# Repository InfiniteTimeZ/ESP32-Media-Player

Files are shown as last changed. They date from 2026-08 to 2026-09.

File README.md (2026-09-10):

# ESP32 Media Player

A desktop-connected media controller built around an ESP32-S3 touchscreen display.

The project combines a Windows desktop companion with an ESP32 touchscreen to display current media information, album artwork, system audio state, and optional Discord voice-channel information while also providing physical and touchscreen media controls.

<p align="center">
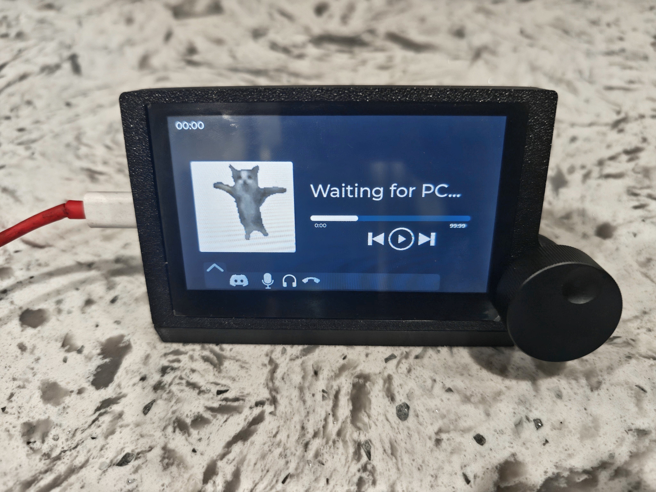
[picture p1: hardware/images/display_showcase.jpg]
ESP32 Media Player
  
</p>

---

## Documentation

| Guide | Purpose |
| --- | --- |
| [Quick Start](docs/QUICK_START.md) | Set up an assembled device |
| [Bill of Materials](hardware/BOM.md) | Parts and reference links |
| [Assembly Guide](hardware/ASSEMBLY.md) | Build the hardware |
| [3D Models](hardware/3d-models/) | Printable housing and stand |
| [Wiring Images](hardware/images/wiring/) | EC11 and CrowPanel pin references |

---

## Features

### Media Display

- Current track title and artist
- 250 × 250 album artwork
- Playback position and duration
- Dynamic interface colors derived from album artwork
- Current system time
- Windows volume and mute state
- Play/pause synchronization

### Controls

**EC11 rotary encoder**
- Rotate — adjust Windows system volume
- Single press — play/pause
- Double press — mute/unmute Windows audio

**Touchscreen**
- Play/pause
- Previous/next track
- Seeking
- Discord voice controls when Discord integration is enabled

### Discord Integration

Optional Discord integration provides:

- Current voice-channel name
- Voice-channel members
- User avatars
- Mute/deafen state
- Voice-channel controls

The interface displays up to **15 voice-channel users** at once.

---

## How It Works

The project is split into two applications:

1. A **Windows desktop companion**
2. Firmware running on the **ESP32-S3 display**

```text
                         Windows PC
┌────────────────────────────────────────────────────────────┐
│                    Desktop Companion                       │
│                                                            │
│  Windows Media ──► media.py                                │
│  Windows Audio ──► Pycaw                                   │
│  Discord ────────► discord_client.py / network.py          │
│                        │                                   │
│                        ▼                                   │
│                    hardware.py                             │
└───────────────────────────┬────────────────────────────────┘
                            │ USB Serial @ 230400 baud
                            ▼
┌────────────────────────────────────────────────────────────┐
│                         ESP32-S3                           │
│                serial_protocol.cpp                         │
│                         │                                  │
│              ┌──────────┴──────────┐                       │
│              ▼                     ▼                       │
│     media_display.cpp       discord_ui.cpp                 │
│                                                            │
│   Touchscreen / Encoder ──► commands back to Windows       │
└────────────────────────────────────────────────────────────┘
```

The desktop companion retrieves Windows and Discord state, sends it to the ESP32 over USB serial, and receives control commands from the display.

---

## Quick Start

1. Flash the ESP32 using the [browser firmware installer](https://infinitetimez.github.io/ESP32-Media-Player/).
2. Download the latest Windows companion from GitHub Releases.
3. Connect the display over USB.
4. Run the desktop companion.
5. Optionally enable Discord integration.

No Python or PlatformIO installation is required when using the prebuilt release files.

For installation details and troubleshooting, continue with the **[Quick Start Guide](docs/QUICK_START.md)**.

---

## Building the Hardware

The repository includes the enclosure files, wiring references, and documentation required to recreate the reference unit.

The reference build uses:

- ELECROW CrowPanel Advance 4.3" 800 × 480 ESP32 HMI Display
- EC11 rotary encoder
- 32 × 13 mm aluminum knob
- M3 heat-set inserts and screws
- Square magnets
- 22 AWG solid-core wire
- Printed display housing and stand

For exact parts, dimensions, and purchase links, see the **[Bill of Materials](hardware/BOM.md)**.

For connector trimming, heat-set inserts, magnet installation, encoder wiring, and final assembly, continue with the **[Assembly Guide](hardware/ASSEMBLY.md)**.

---

## EC11 Encoder Wiring

| EC11 Pin / Function | ESP32 Connection |
| --- | --- |
| A | GPIO 19 |
| B | GPIO 20 |
| C / Common | GND |
| Push switch | GPIO 8 |
| Remaining switch terminal | GND |

The push-switch terminals are interchangeable. If clockwise rotation decreases volume instead of increasing it, swap **A** and **B**.

See the labeled references in [`hardware/images/wiring/`](hardware/images/wiring/) or the **[Assembly Guide](hardware/ASSEMBLY.md)** for full wiring notes.

---

## Serial Protocol

Desktop-to-ESP32 application traffic uses a framed binary protocol:

```text
A5 5A | TYPE | uint32 LE LENGTH | PAYLOAD
```

| Type | Payload | Purpose |
| --- | --- | --- |
| `R` | None | ESP32 readiness |
| `T` | JSON | Track/media state |
| `I` | JPEG | Album artwork |
| `U` | JSON | Discord voice roster |
| `A` | Index + JPEG | Discord user avatar |
| `D` | State bytes | Discord mute/deafen state |
| `N` | Text | Discord voice-channel name |

The firmware parser can recover from incomplete or corrupted data by searching for the next valid frame boundary. Large image packets are sent in smaller chunks to avoid overwhelming the ESP32 receive path.

---

## Project Structure

```text
ESP32-Media-Player/
├── desktop-companion/
│   ├── assets/
│   ├── main.py
│   ├── hardware.py
│   ├── media.py
│   ├── network.py
│   ├── discord_client.py
│   ├── config.py
│   ├── requirements.txt
│   └── PyInstaller spec files
│
├── firmware/
│   ├── boards/
│   ├── include/
│   ├── src/
│   │   ├── components/
│   │   ├── images/
│   │   ├── screens/
│   │   ├── main.cpp
│   │   ├── serial_protocol.cpp
│   │   ├── media_display.cpp
│   │   ├── discord_ui.cpp
│   │   └── music_player_logic.c
│   ├── partitions.csv
│   ├── platformio.ini
│   ├── sdkconfig.defaults
|   └── sdkconfig.defaults.esp32s3
│
├── hardware/
│   ├── 3d-models/
│   ├── images/
│   ├── ASSEMBLY.md
│   └── BOM.md
│
├── docs/
│   ├── firmware/
│   ├── index.html
│   ├── manifest.json
│   └── QUICK_START.md
│
├── README.md
├── LICENSE
└── .gitignore
```

---

## Running From Source

### Desktop Companion

Requirements:

- Windows
- Python 3
- Discord desktop client if using Discord integration

```powershell
cd desktop-companion
python -m venv .venv
.\.venv\Scripts\Activate.ps1
pip install -r requirements.txt
python main.py
```

### ESP32 Firmware

The firmware is built with PlatformIO:

```bash
cd firmware
pio run
pio run --target upload
```

Serial communication uses **230400 baud**.

---

## Discord Setup

Discord integration is optional.

1. Create an application in the [Discord Developer Portal](https://discord.com/developers/applications).
2. Copy the **Application ID** and **Client Secret**.
3. Add this OAuth2 redirect URI:

```text
http://127.0.0.1
```

4. Enable **Discord Integration** from the desktop companion's system-tray menu.
5. Enter the requested credentials and restart the companion.

> Keep the Client Secret private. Do not commit it to GitHub or include it in screenshots.

---

## Releases

Prebuilt Windows builds and merged ESP32 firmware images are available on the GitHub Releases page.

The ESP32 can also be flashed directly using the [browser firmware installer](https://infinitetimez.github.io/ESP32-Media-Player/).

---

## Known Limitations

- The desktop companion currently supports Windows only.
- Firmware configuration targets the reference ELECROW display hardware.
- The Discord interface displays up to 15 visible voice-channel users.
- Album artwork depends on thumbnail data supplied by the active Windows media application.

---

## Project Status

This was primarily a summer project, and since I'm a student, updates may be inconsistent depending on how busy I am.

If you run into an issue, feel free to open one and I'll get to it when I can.

---

## License

Licensed under the GNU General Public License v3.0. See [`LICENSE`](LICENSE) for details.

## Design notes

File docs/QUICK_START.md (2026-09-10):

# Quick Start

This guide continues from the main README and is intended for users who already have the ESP32 Media Player assembled.

## 1. Flash the ESP32

The easiest installation method is the [browser firmware installer](https://infinitetimez.github.io/ESP32-Media-Player/).

Use a current desktop version of **Google Chrome** or **Microsoft Edge**.

1. Connect the CrowPanel to the computer over USB.
2. Close the desktop companion and any serial-monitoring software.
3. Open the browser installer.
4. Click **Install Firmware**.
5. Select the ESP32-S3 device.
6. Wait for installation to finish and allow the display to restart.

The installer flashes the complete merged firmware image automatically. No PlatformIO installation or manual flash offsets are required.

### Manual Firmware Installation

The merged firmware image is also available from GitHub Releases.

If flashing manually, write the merged image beginning at:

```text
0x0000
```

## 2. Install the Windows Companion

Download the latest Windows executable from GitHub Releases and run it.

The application runs from the Windows system tray.

## 3. Connect the Display

Connect the ESP32 Media Player over USB. The desktop companion automatically searches for the device and establishes the serial connection.

Once connected, the display should begin showing media information, album artwork, playback position, system volume, and the current time.

## 4. Controls

### Rotary Encoder

- Rotate — change Windows volume
- Single press — play/pause
- Double press — mute/unmute Windows audio

### Touchscreen

- Play/pause
- Previous/next track
- Seeking
- Supported Discord voice controls

## 5. Optional Discord Integration

Enable **Discord Integration** from the companion's system-tray menu and enter your Discord application credentials when prompted.

Discord must be running locally.

For Discord application setup, see the **Discord Setup** section in the main README.

## Troubleshooting

### Display is not connecting

- Confirm the ESP32 is connected over USB.
- Close any other program using the ESP32 serial port.
- Restart the desktop companion.
- Disconnect and reconnect the ESP32.

### Display connects but does not update

Restart the desktop companion and reconnect the display.

### Album artwork is stale

Some Windows media applications provide delayed thumbnail data. The companion retries artwork retrieval several times when a new track is detected, but stale artwork can still occur.

### Discord information is missing

- Confirm Discord is running.
- Confirm Discord integration is enabled.
- Verify the Discord application credentials.
- Restart the desktop companion after first-time setup.

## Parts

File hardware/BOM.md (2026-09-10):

# Bill of Materials

This page continues from the hardware overview in the main README and lists the parts used in the reference ESP32 Media Player build.

## Main Components

| Component | Qty. | Specification | Reference Link | Notes |
| --- | ---: | --- | --- | --- |
| ESP32 Touch Display | 1 | ELECROW CrowPanel Advance 4.3", 800 × 480 IPS touch display | [ELECROW](https://www.elecrow.com/crowpanel-advance-4-3-hmi-esp32-800x480-ai-display-ips-touch-artificial-intelligent-screen.html) | Reference display hardware |
| Rotary Encoder | 1 | EC11 with push switch, 15 mm D-shaft | [Amazon](https://www.amazon.com/dp/B07D3D64X7) | Volume, play/pause, and mute |
| Encoder Knob | 1 | 32 × 13 mm aluminum knob for 6 mm shaft | [Amazon](https://www.amazon.com/dp/B07X7RDQ1W) | Fits the reference EC11 |
| M3 Heat-Set Inserts | 4 | M3 brass threaded inserts | [Amazon](https://www.amazon.com/dp/B0FWWW8VP1) | Used with enclosure mounting points |
| M3 × 12 Screws | 4 | M3 Phillips machine screws | [Amazon](https://www.amazon.com/dp/B0D1CRFR6Z) | Used with the heat-set inserts |
| Square Magnets | 2 | 1.26" × 1.26", 2 mm thick | [Amazon](https://www.amazon.com/dp/B0GQ47BZJS) | Housing-to-stand attachment |
| Hookup Wire | As needed | 22 AWG solid-core wire | [Amazon](https://www.amazon.com/dp/B07TX6BX47) | Encoder and internal wiring |

## 3D-Printed Parts

| Part | Qty. | File |
| --- | ---: | --- |
| Display Housing | 1 | [`Display_Housing_Print.stl`](3d-models/Display_Housing_Print.stl) |
| Stand | 1 | [`Stand_Print.stl`](3d-models/Stand_Print.stl) |

Reference printing:

- **Material:** PETG-HF
- **Supports:** not required
- **Orientation:** STL files are already oriented as used for the reference prints

## Additional Notes

**Magnets:** The reference magnets include adhesive. Approximately **1 mm double-sided tape** can be used as a replacement. Confirm magnet orientation before permanent installation.

**Display connector clearance:** The four beige connector housings on the CrowPanel must be trimmed to fit inside the enclosure. Advanced builders can desolder the connectors and wire directly to the PCB instead.

For wiring, heat-set insert installation, connector trimming, and final assembly, continue with the **[Assembly Guide](ASSEMBLY.md)**.

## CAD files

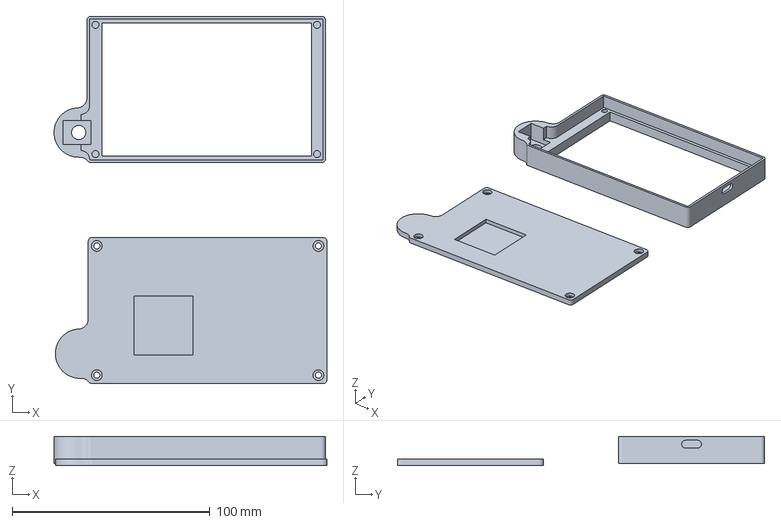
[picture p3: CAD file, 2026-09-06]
hardware/3d-models/Display_Housing.3mf
138.0 x 185.8 x 14.7 mm

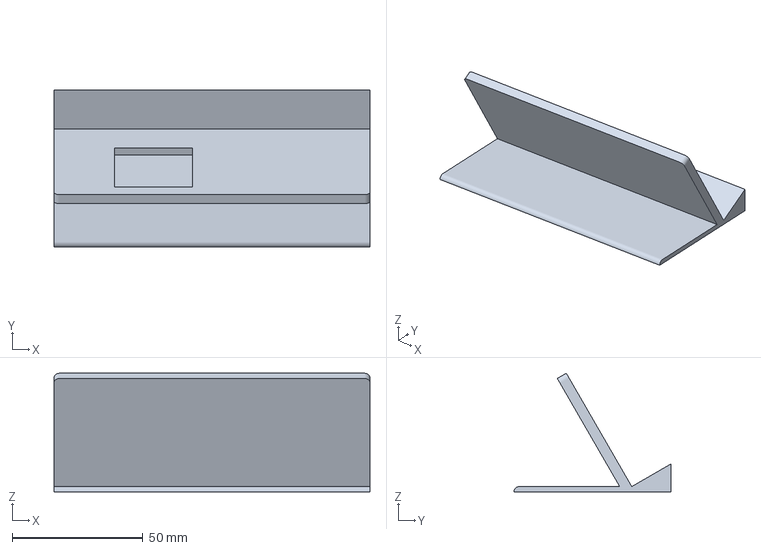
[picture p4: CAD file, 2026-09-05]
hardware/3d-models/Stand_Print.3mf
120.7 x 60.0 x 45.3 mm

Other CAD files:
hardware/3d-models/Display_Housing_Print.stl
hardware/3d-models/Complete_Housing_Assembly.f3d
hardware/3d-models/Stand_Print.stl

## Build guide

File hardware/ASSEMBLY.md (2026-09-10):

# Hardware Assembly Guide

This guide continues from the hardware overview in the main README and covers the reference ESP32 Media Player assembly.

For exact parts and purchase links, see the **[Bill of Materials](BOM.md)**.

## Tools

Recommended tools:

- Soldering iron
- Small Phillips screwdriver
- Flush cutters or hobby knife
- Heat-set insert tip or suitable soldering-iron tip
- Wire strippers
- Solder

## 1. Print the Enclosure

Print both files from [`3d-models/`](3d-models/):

- `Display_Housing_Print.stl`
- `Stand_Print.stl`

Reference print setup:

- **Material:** PETG-HF
- **Supports:** not required
- **Orientation:** the STL files are already oriented as used for the reference prints

Other suitable materials should also work, though support requirements may vary.

## 2. Prepare the Display Board

The four beige connector housings on the display board are too tall to fit inside the printed enclosure.

Carefully trim the housings until the board clears the inside of the case.

**Advanced alternative:** desolder the connector housings and wire directly to the PCB. This provides more clearance but carries a greater risk of damaging the board.

## 3. Install the Heat-Set Inserts

Install **4 M3 heat-set inserts**.

For PETG-HF, approximately **270 °C** worked well.

- Apply light, steady pressure.
- Allow the heat to soften the plastic rather than forcing the insert.
- Stop once the insert is flush.
- Let the plastic cool before installing screws.

Adjust the temperature as needed for the filament being used.

## 4. Install the Magnets

Use **2 square magnets** measuring:

- 1.26 in × 1.26 in
- 2 mm thick

Install one magnet in the housing and one in the stand. Dry-fit both parts first and verify that the magnets attract each other before attaching them permanently.

The reference magnets include adhesive. If you need replacement adhesive, use about **1 mm double-sided tape**. Thinner adhesive is better for a flush magnet fitment.
## 5. Wire the EC11 Encoder

| Encoder Pin / Function | ESP32 |
| --- | --- |
| A | GPIO 19 |
| B | GPIO 20 |
| C / Common | GND |
| D or E / Push switch | GPIO 8 |
| Remaining switch terminal | GND |

The two push-switch terminals are interchangeable.

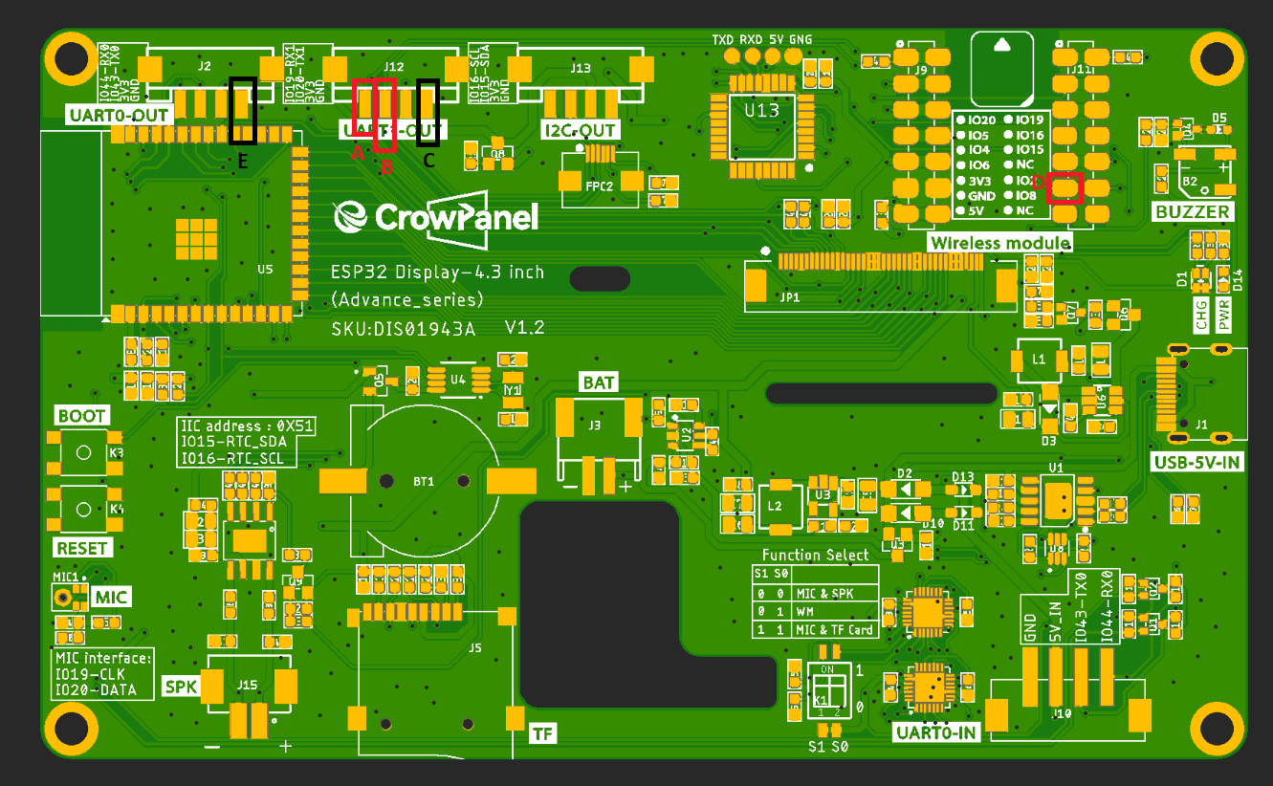
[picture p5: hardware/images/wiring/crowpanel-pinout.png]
CrowPanel GPIO reference


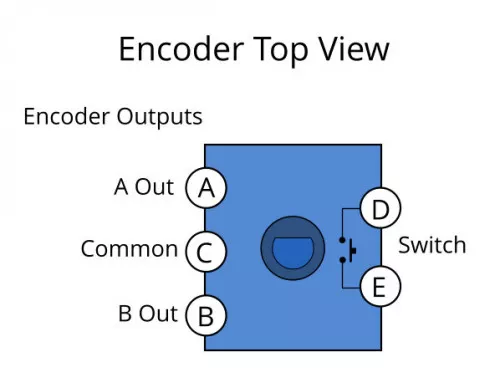
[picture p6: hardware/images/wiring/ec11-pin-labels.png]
EC11 labeled pins


> If clockwise rotation lowers volume instead of raising it, swap A and B.

## 6. Mount the Encoder and Knob

1. Secure the EC11 using its washer and nut.
2. Confirm the shaft rotates freely and the push action is unobstructed.
3. Install the 32 × 13 mm aluminum knob onto the 6 mm shaft.

## 7. Mount the Display

1. Confirm the trimmed connectors or direct wiring clear the enclosure.
2. Position the display without pinching any wires.
3. Check that internal wiring cannot short against the board.
4. Secure the display using the M3 hardware.

## 8. Flash and Test

Continue with the **[Quick Start Guide](../docs/QUICK_START.md)**.

Verify:

- Display boots
- Desktop companion connects
- Track information and album art update
- Encoder controls volume, play/pause, and mute
- Touchscreen controls work
- Discord UI updates correctly when enabled

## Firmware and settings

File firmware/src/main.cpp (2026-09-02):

#include "pins_config.h"
#include "LovyanGFX_Driver.h"
#include <Arduino.h>
#include <lvgl.h>
#include <Wire.h>
#include <SPI.h>
#include <stdbool.h>
#include "ui.h"
#include "music_player_logic.h"
#include "serial_protocol.h"
#include "discord_ui.h"
#include "media_display.h"

LGFX gfx;
static uint8_t *buf;
static uint8_t *buf1;
constexpr uint32_t LVGL_BUFFER_LINES = 60;
uint16_t touch_x, touch_y;
uint32_t vol_lockout_timer = 0;

#define ENC_PIN_A 19
#define ENC_PIN_B 20
#define ENC_PIN_D 8

constexpr uint32_t DOUBLE_CLICK_TIME = 450;

volatile int32_t encoder_counter = 0;
volatile uint8_t encoder_history = 0;
int32_t last_pos = 0;
int currentVolume = 25;

bool is_system_muted = false; 

static const int8_t KNOB_STATES[] = {0, -1, 1, 0, 1, 0, 0, -1, -1, 0, 0, 1, 0, 1, -1, 0};

void uart_error(hardwareSerial_error_t error){
  Serial.printf("UART ERROR: %d\n", error);
}


void IRAM_ATTR encoder_isr() {
    encoder_history <<= 2;
    encoder_history |= (digitalRead(ENC_PIN_A) << 1) | digitalRead(ENC_PIN_B);
    int8_t movement = KNOB_STATES[encoder_history & 0x0F];
    if (movement != 0) {
        encoder_counter += movement;
    }
}


void setup_encoder() {
    pinMode(ENC_PIN_A, INPUT_PULLUP);
    pinMode(ENC_PIN_B, INPUT_PULLUP);
    pinMode(ENC_PIN_D, INPUT_PULLUP);
    attachInterrupt(digitalPinToInterrupt(ENC_PIN_A), encoder_isr, CHANGE);
    attachInterrupt(digitalPinToInterrupt(ENC_PIN_B), encoder_isr, CHANGE);
}


void my_encoder_read(lv_indev_t *indev, lv_indev_data_t *data) {
    int32_t diff = encoder_counter - last_pos;
    last_pos = encoder_counter;
    if (diff > 0) data->enc_diff = 1;
    else if (diff < 0) data->enc_diff = -1;
    else data->enc_diff = 0;
    data->state = (digitalRead(ENC_PIN_D) == LOW) ? LV_INDEV_STATE_PRESSED : LV_INDEV_STATE_RELEASED;
}


void my_disp_flush(lv_display_t *disp, const lv_area_t *area, uint8_t *px_map) {
    uint32_t w = area->x2 - area->x1 + 1;
    uint32_t h = area->y2 - area->y1 + 1;

    gfx.startWrite();
    gfx.pushImageDMA(area->x1, area->y1, w, h, (lgfx::rgb565_t *)px_map);
    gfx.endWrite(); 
    
    lv_display_flush_ready(disp);
}


void my_touchpad_read(lv_indev_t *indev, lv_indev_data_t *data) {
    data->state = LV_INDEV_STATE_REL;
    bool touched = gfx.getTouch(&touch_x, &touch_y);
    if (touched) {
        data->state = LV_INDEV_STATE_PR;
        data->point.x = touch_x;
        data->point.y = touch_y;
    }
}


uint32_t my_tick_get_cb() {
    return millis();
}


 bool i2cScanForAddress(uint8_t address) {
    Wire.beginTransmission(address);
    return (Wire.endTransmission() == 0);
}


void sendI2CCommand(uint8_t command) {
    uint8_t error;
    Wire.beginTransmission(0x30);
    Wire.write(command);
    error = Wire.endTransmission();
    if (error == 0) {
        Serial.print("command 0x");
        Serial.print(command, HEX);
        Serial.println(" Sent successfully");
    } else {
        Serial.print("Command sent error, error code:");
        Serial.println(error);
    }
}


 void handle_volume_logic() {
    static int32_t last_volume_pos = 0;
    static uint32_t last_click_time = 0; 
    
    int32_t current_pos = encoder_counter / 4;

    static uint32_t interaction_timer = 0;
    static int current_opacity = 0; 
    static bool is_active = false;

    if (current_pos != last_volume_pos) {
        int32_t diff = current_pos - last_volume_pos;
        last_volume_pos = current_pos;

        uint32_t current_time = millis();
        uint32_t time_between_clicks = current_time - last_click_time;
        last_click_time = current_time;

        int step_multiplier = 1;  
        
        if (time_between_clicks < 50) {
            step_multiplier = 10; 
        } else if (time_between_clicks < 120) {
            step_multiplier = 5;  
        } else if (time_between_clicks < 250) {
            step_multiplier = 2;  
        }

        currentVolume += (diff * step_multiplier);
 
        if (currentVolume > 100) currentVolume = 100;
        if (currentVolume < 0) currentVolume = 0;

        Serial.print("CMD:VOL:");
        Serial.println(currentVolume);

        if (is_system_muted) {
            is_system_muted = false;
            update_mute_visuals();
        }

        vol_lockout_timer = millis();

        lv_bar_set_value(ui_Bar1, currentVolume, LV_ANIM_OFF);

        char str_buf[8];
        snprintf(str_buf, sizeof(str_buf), "%d%%", currentVolume);
        lv_label_set_text(ui_Vol_Percent, str_buf);

        if (!is_active) {
            lv_obj_remove_flag(ui_Volume_Panel, LV_OBJ_FLAG_HIDDEN);
            is_active = true;
        }

        interaction_timer = millis();
    }

    if (is_active) {
        uint32_t time_elapsed = millis() - interaction_timer;

        if (time_elapsed < 2000) {
            if (current_opacity < 255) {
                current_opacity += 51; 
                if (current_opacity > 255) current_opacity = 255;
                lv_obj_set_style_opa(ui_Volume_Panel, current_opacity, LV_PART_MAIN);
            }
        } else {
            if (current_opacity > 0) {
                current_opacity -= 25; 
                if (current_opacity < 0) current_opacity = 0;
                lv_obj_set_style_opa(ui_Volume_Panel, current_opacity, LV_PART_MAIN);
            } else {
                lv_obj_add_flag(ui_Volume_Panel, LV_OBJ_FLAG_HIDDEN);
                is_active = false;
            }
        }
    }
}


void setup_serial(){
    size_t rx_size = Serial.setRxBufferSize(1024 * 40);
    Serial.begin(230400);  
    Serial.setRxFIFOFull(64);
    Serial.onReceiveError(uart_error);
    Serial.printf("Serial RX buffer allocated: %u bytes\n", rx_size);
}


void setup_controllers(){
    Wire.begin(15, 16);
    delay(50);

    while (true) {
        if (i2cScanForAddress(0x30) && i2cScanForAddress(0x5D)) {
            Serial.println("Both controllers detected");
            break;
        } else {
            sendI2CCommand(250);
            pinMode(1, OUTPUT);
            digitalWrite(1, LOW);
            delay(120);
            pinMode(1, INPUT);
            delay(100);
        }
    }
    sendI2CCommand(0);
}

void setup_display(){
    
    gfx.init();
    gfx.initDMA(); 
    
    gfx.startWrite();
    gfx.fillScreen(TFT_BLACK);
    gfx.endWrite();

    lv_init();
    lv_tick_set_cb(my_tick_get_cb);

    constexpr size_t buffer_size = LCD_H_RES * LVGL_BUFFER_LINES * sizeof(uint16_t);
    
    buf = static_cast<uint8_t *>(heap_caps_malloc(buffer_size, MALLOC_CAP_INTERNAL | MALLOC_CAP_DMA));
    buf1 = static_cast<uint8_t *>(heap_caps_malloc(buffer_size, MALLOC_CAP_INTERNAL | MALLOC_CAP_DMA));
    
    if (buf == nullptr || buf1 == nullptr) {
        Serial.println("Failed to allocate INTERNAL LVGL display buffers");
        abort();
    }

    lv_display_t *display = lv_display_create(LCD_H_RES, LCD_V_RES);
    lv_display_set_color_format(display, LV_COLOR_FORMAT_RGB565);
    lv_display_set_flush_cb(display, my_disp_flush);
    lv_display_set_buffers(display, buf, buf1, buffer_size, LV_DISPLAY_RENDER_MODE_PARTIAL);

    lv_indev_t *indev = lv_indev_create();
    lv_indev_set_type(indev, LV_INDEV_TYPE_POINTER);
    lv_indev_set_read_cb(indev, my_touchpad_read);

    setup_encoder();
    
    lv_indev_t *encoder_indev = lv_indev_create();
    lv_indev_set_type(encoder_indev, LV_INDEV_TYPE_ENCODER);
    lv_indev_set_read_cb(encoder_indev, my_encoder_read);
}

void setup_ui(){
    delay(100);
    gfx.fillScreen(TFT_BLACK);

    ui_init();
    register_screen_switch_handlers();
    lv_obj_set_parent(ui_Volume_Panel, lv_layer_top());
    lv_obj_set_parent(ui_TimeLabel, lv_layer_top());
    lv_obj_set_style_text_color(ui_TimeLabel, lv_color_hex(0xFFFFFF), LV_PART_MAIN);
    lv_obj_add_event_cb(ui_SongPositionSlider, track_slider_cb, LV_EVENT_PRESSED, NULL);
    lv_obj_add_event_cb(ui_SongPositionSlider, track_slider_cb, LV_EVENT_RELEASED, NULL);
    music_player_init();
    
    lv_obj_add_flag(ui_Volume_Panel, LV_OBJ_FLAG_HIDDEN);
    init_serial_protocol();
    init_media_display();
    init_discord_ui_buffers();

    char str_buf[8];
    snprintf(str_buf, sizeof(str_buf), "%d%%", currentVolume);
    lv_label_set_text(ui_Vol_Percent, str_buf);

    last_pos = encoder_counter;
}

void signal_ready(){

    while (Serial.available() > 0) {
        Serial.read();
    }
      
    delay(50);
    Serial.println();
    Serial.println("ESP32_READY");
}


void handle_encoder_button(){
    static int lastButtonState = HIGH;
    static uint32_t last_button_click_time = 0;
    static bool pending_single_click = false;
   

    int currentButtonState = digitalRead(ENC_PIN_D); 

    if (currentButtonState != lastButtonState) {
        delay(10); 
        currentButtonState = digitalRead(ENC_PIN_D); 
        if (currentButtonState != lastButtonState) {
            lastButtonState = currentButtonState;
            
            if (currentButtonState == LOW) { 
                if (pending_single_click && (millis() - last_button_click_time < DOUBLE_CLICK_TIME)) {
                    Serial.println("CMD:MUTE");
                    is_system_muted = !is_system_muted;
                    update_mute_visuals();
                    pending_single_click = false;

                } else {
                     pending_single_click = true;
                }
                 last_button_click_time = millis();
            }
        }
       
    }  
    if (pending_single_click && (millis() - last_button_click_time > DOUBLE_CLICK_TIME)) {
        Serial.println("CMD:TOGGLE");
        pending_single_click = false;    
    }
}


 void setup() {
    setup_serial();
    setup_controllers();
    setup_display();
    setup_ui();
    
    Serial.println("Setup done");

    signal_ready(); 
}

void loop() {
    lv_timer_handler();
    handle_volume_logic();
    handle_serial_input();
    handle_encoder_button();

    delay(1);
}

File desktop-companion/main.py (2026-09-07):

import asyncio
import logging
import os
import shutil
import sys
import threading
import time

from PIL import Image
import pystray
from pystray import MenuItem as item

import config
import hardware
import media
import network


is_paused = False
logger = logging.getLogger(__name__)

class MediaSyncState:
    def __init__(self):
        self.last_processed_track = None
        self.last_resync_time = 0
        self.last_known_position = 0
        self.last_sent_signature = None


def configure_logging():
    logging.basicConfig(
        level=logging.INFO,
        format="%(asctime)s | %(levelname)-8s | %(name)s | %(message)s",
        datefmt="%H:%M:%S",
    )


def track_signature(track_info):
    return (track_info.get("title"), track_info.get("artist"), track_info.get("album"), track_info.get("duration"), track_info.get("playback_status"), track_info.get("volume"), track_info.get("is_muted"), track_info.get("time"))


async def connect_hardware():
    if not hardware.connect():
        await asyncio.sleep(2)
        return False

    logger.info("Serial connected; waiting for ESP32 ready signal")

    deadline = time.monotonic() + 8
    next_probe = 0

    while time.monotonic() < deadline:
        now = time.monotonic()
                        
        #Retry slowly enough that an interrupted parser has time to reach
        # its 1.5 second stall recovery before next probe
        if now >= next_probe:
            hardware.request_ready()
            logger.info("Sent ESP32 readiness probe")
            next_probe = now + 2.0
            
        lines = hardware.read_incoming()
            
        if any("ESP32_READY" in line for line in lines):
            logger.info("ESP32 ready signal received")
            hardware.mark_ready_for_sync()
            network.resync_hardware()
            return True

        await asyncio.sleep(0.1)

    logger.warning("ESP32 ready signal was not received before timeout; reconnecting")

    hardware.disconnect()
    await asyncio.sleep(1)
    return False


async def handle_incoming_commands(session_manager, discord_rpc):
    incoming_commands = hardware.read_incoming()
    for clean_line in incoming_commands:
        logger.debug("UART received: %s", clean_line)

        if "Serial stall detected" in clean_line or "Corrupt stream detected" in clean_line  or "Serial packet timeout" in clean_line or "Invalid packet" in clean_line or "JPEG decode failed" in clean_line:

            logger.warning("ESP32 serial parser reported: %s", clean_line)
            continue

        if clean_line in ["CMD:NEXT", "CMD:PREV", "CMD:TOGGLE"] or clean_line.startswith("CMD:SEEK:"):
            await media.handle_media_command(session_manager, clean_line)

        elif clean_line == "CMD:MUTE":
            media.toggle_windows_mute()

        elif clean_line.startswith("CMD:VOL:"):
            try:
                volume = int(clean_line.split(":")[2])
                media.set_windows_volume(volume)
            except ValueError:
                logger.warning("Received invalid volume command: %s", clean_line)

        elif clean_line.startswith("CMD:TOGGLE_") or clean_line == "CMD:LV_CALL":
            asyncio.create_task(network.handle_discord_commands(discord_rpc, clean_line))


async def sync_current_media(session_manager, state):
    track_info, state.last_processed_track, new_art = (await media.get_current_track_info(session_manager, state.last_processed_track))

    if track_info:
        sig = track_signature(track_info)
        now = asyncio.get_running_loop().time()

        current_pos = track_info["position"]
        is_seek = abs(current_pos - state.last_known_position) > 3.0         
                
        if sig != state.last_sent_signature:
            hardware.send_track_info(track_info)
            state.last_sent_signature = sig
            state.last_resync_time = now
        elif is_seek or (now - state.last_resync_time) > 5: 
            hardware.send_track_info(track_info)
            state.last_resync_time = now
    
        state.last_known_position = current_pos
    
    if new_art: 
        hardware.send_album_art(new_art)


async def main_loop():

    hardware.start()
    media.start()

    sync_state = MediaSyncState()
    session_manager = await media.MediaManager.request_async()
    

    discord_rpc = None
    if config.app_config.get("use_discord"):
        discord_rpc = await network.init_discord_rpc()

    while True:
        if is_paused:
            hardware.disconnect()
            await asyncio.sleep(1)
            continue
                
        if not hardware.is_connected():
            if not await connect_hardware():
                continue
                     
            sync_state.last_sent_signature = None
            sync_state.last_processed_track = None
            sync_state.last_resync_time = asyncio.get_running_loop().time()

        await handle_incoming_commands(session_manager, discord_rpc)
        await sync_current_media(session_manager, sync_state)

        await asyncio.sleep(0.6)



def toggle_pause(icon, item):
    global is_paused
    is_paused = not item.checked


def toggle_discord(icon, item):
    enabled = not item.checked

    if enabled:
        if not config.app_config.get("discord_client_id") or not config.app_config.get("discord_client_secret"):
            def enable_discord_callback():
                config.app_config["use_discord"] = enabled
                config.save_config()
                logger.info("Discord credentials saved; restart required")
            config.prompt_for_discord_credentials(enable_discord_callback)
            return
    config.app_config["use_discord"] = enabled
    config.save_config()
    logger.info("Discord integration setting updated; restart required")


def set_windows_startup(enabled):
    startup_folder = os.path.join(os.getenv('APPDATA'), r"Microsoft\Windows\Start Menu\Programs\Startup")
    exe_name = os.path.basename(sys.executable)
    startup_path = os.path.join(startup_folder, exe_name)

    if enabled:
        try:
            shutil.copy(sys.executable, startup_path)
            logger.info("Enabled Windows startup")
        except Exception:
            logger.exception("Failed to enable Windows startup")

    elif os.path.exists(startup_path):
        try:
            os.remove(startup_path)
            logger.info("Disabled Windows startup")
        except Exception:
            logger.exception("Failed to disable Windows startup")


def toggle_startup(icon, item):
    enabled = not item.checked

    config.app_config["run_on_startup"] = enabled
    config.save_config()

    set_windows_startup(enabled)



def quit_app(icon, item):
    icon.stop()
    os._exit(0)


def resource_path(relative_path):
    if hasattr(sys, "_MEIPASS"):
        return os.path.join(sys._MEIPASS, relative_path)
    return os.path.join(os.path.dirname(__file__), relative_path)
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

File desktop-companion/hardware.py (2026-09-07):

import json
import logging
import queue
import struct
import threading
import time

import serial
import serial.tools.list_ports

ESP32_VID = 0x1A86
KNOWN_CH340_PIDS = {0x7522, 0x7523, 0x5523}
_PACKET_MAGIC = b"\xA5\x5A"

connection = None
uart_buffer = ""
_ready_for_sync = False
_writer_thread = None
_latest_album_art_packet = None
_album_art_token_queued = False
logger = logging.getLogger(__name__)

_write_lock = threading.RLock()
_write_queue = queue.Queue()
_album_art_lock = threading.Lock()
_album_art_token = object()


def _build_packet(packet_type, payload=b""):
    if not isinstance(packet_type, bytes) or len(packet_type) != 1:
        raise ValueError("packet_type must be exactly one byte")

    return (_PACKET_MAGIC + packet_type + struct.pack("<I", len(payload)) + payload)


def _write_packet(serial_connection, data):
    chunk_size = 128

    for i in range(0, len(data), chunk_size):
        chunk = data[i:i + chunk_size]
        serial_connection.write(chunk)

        if i + chunk_size < len(data):
            time.sleep(0.005)

    serial_connection.flush()


def _clear_write_queue():
    while True:
        try:
            _write_queue.get_nowait()
            _write_queue.task_done()
        except queue.Empty:
            break



def _clear_pending_album_art():
    global _latest_album_art_packet, _album_art_token_queued

    with _album_art_lock:
        _latest_album_art_packet = None
        _album_art_token_queued = False


def _serial_writer():
    global _latest_album_art_packet, _album_art_token_queued

    while True:
        item = _write_queue.get()
        serial_connection = None

        try:
            if item is None:
                break

            if item is _album_art_token:
                with _album_art_lock:
                    data = _latest_album_art_packet
                    _latest_album_art_packet = None
                    _album_art_token_queued = False

                if data is None:
                    continue

                is_large = True

            else:
                is_large, data = item

            with _write_lock:
                serial_connection = connection
            
                if (serial_connection is None or not serial_connection.is_open):
                    continue

                logger.debug( "Sending serial packet: %d bytes, large=%s", len(data), is_large)    
                _write_packet(serial_connection, data)
                if is_large:
                    time.sleep(0.10)
            
        except(serial.SerialException, OSError) as exc:
            logger.warning("ESP32 serial connection lost: %s", exc)
            disconnect(expected_connection=serial_connection)
                        
        finally:
            _write_queue.task_done()


def start():
    global _writer_thread

    if _writer_thread is not None and _writer_thread.is_alive():
        return

    _writer_thread = threading.Thread(target=_serial_writer, name="esp32-serial-writer", daemon=True)
    _writer_thread.start()
    logger.debug("ESP32 serial writer started")


def find_esp32_port():
    ports = serial.tools.list_ports.comports()
    for port in ports:
        if port.vid == ESP32_VID and port.pid in KNOWN_CH340_PIDS:
            return port.device
    return None


def connect():
    global connection, uart_buffer, _ready_for_sync

    if connection and connection.is_open:
        return True

    port_name = find_esp32_port()

    if not port_name:
        return False

    with _write_lock:
        try:
            _ready_for_sync = False
            uart_buffer = ""
            _clear_write_queue()
            _clear_pending_album_art()
            connection = serial.Serial(port_name, 230400, timeout=1)
            logger.info("Connected to ESP32 on %s", port_name)
            return True
        except serial.SerialException:
            logger.exception("Failed to connect to ESP32 on %s", port_name)
            return False

        
def disconnect(expected_connection=None):
    global connection, uart_buffer, _ready_for_sync

    with _write_lock:
        if expected_connection is not None and connection is not expected_connection:
            return

        _ready_for_sync = False
        _clear_write_queue()
        _clear_pending_album_art()

        if connection:
            try:
                connection.close()
            except serial.SerialException:
                logger.exception("Error while closing ESP32 serial connection")
            finally:
                connection = None

        uart_buffer = ""


def is_connected():
    return connection is not None and connection.is_open

def is_ready_for_sync():
    return is_connected() and _ready_for_sync


def read_incoming():
    global uart_buffer
    if not is_connected():
        return []
    try:
        if connection.in_waiting > 0:
            uart_buffer += connection.read(connection.in_waiting).decode('utf-8', errors='ignore')
        if '\n' in uart_buffer:
            lines = uart_buffer.split('\n')
            uart_buffer = lines.pop()
            return [line.strip() for line in lines if line.strip()]
        return []
    except (serial.SerialException, OSError) as exc:
        logger.warning("ESP32 serial connection lost: %s", exc)
        disconnect()
        return []

    
def request_ready():
    serial_connection = None

    try: 
        with _write_lock:
            serial_connection = connection

            if (serial_connection is None or not serial_connection.is_open):
                return False

            packet = _build_packet(b"R")
            serial_connection.write(packet)
            serial_connection.flush()
            return True
        
    except(serial.SerialException, OSError) as exc:
        logger.warning("Failed to request ESP32 ready state: %s", exc)
        disconnect(expected_connection=serial_connection)
        return False
    

def mark_ready_for_sync():
    global _ready_for_sync
    _ready_for_sync = is_connected()


def send_track_info(track_info):
    if not is_ready_for_sync(): 
        return
    
    payload = json.dumps(track_info).encode("utf-8")
    packet = _build_packet(b"T", payload)
    _write_queue.put((False, packet))


def send_album_art(jpeg_bytes):
    global _latest_album_art_packet, _album_art_token_queued

    if not is_ready_for_sync():
        return

    packet = _build_packet(b"I", jpeg_bytes)

    with _album_art_lock:
        _latest_album_art_packet = packet

        if _album_art_token_queued:
            logger.debug("Replaced pending album art: %d bytes", len(jpeg_bytes))
            return

        _album_art_token_queued = True

    logger.debug("Queueing album art: %d bytes", len(jpeg_bytes))
    _write_queue.put(_album_art_token)
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

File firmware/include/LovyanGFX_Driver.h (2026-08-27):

#define LGFX_USE_V1
#include <LovyanGFX.hpp>
#include <lgfx/v1/platforms/esp32s3/Panel_RGB.hpp>
#include <lgfx/v1/platforms/esp32s3/Bus_RGB.hpp>
#include <driver/i2c.h>

class LGFX : public lgfx::LGFX_Device {
public:

  lgfx::Bus_RGB _bus_instance;
  lgfx::Panel_RGB _panel_instance;
  lgfx::Touch_GT911 _touch_instance;

  LGFX(void) {
    {
      auto cfg = _panel_instance.config();

      cfg.memory_width = 800;
      cfg.memory_height = 480;
      cfg.panel_width = 800;
      cfg.panel_height = 480;

      cfg.offset_x = 0;
      cfg.offset_y = 0;

      _panel_instance.config(cfg);
    }

    {
      auto cfg = _panel_instance.config_detail();

      cfg.use_psram = 1;

      _panel_instance.config_detail(cfg);
    }

    {
      auto cfg = _bus_instance.config();
      cfg.panel = &_panel_instance;
      cfg.pin_d0 = GPIO_NUM_21;    // B0
      cfg.pin_d1 = GPIO_NUM_47;    // B1
      cfg.pin_d2 = GPIO_NUM_48;   // B2
      cfg.pin_d3 = GPIO_NUM_45;    // B3
      cfg.pin_d4 = GPIO_NUM_38;    // B4
      cfg.pin_d5 = GPIO_NUM_9;    // G0
      cfg.pin_d6 = GPIO_NUM_10;    // G1
      cfg.pin_d7 = GPIO_NUM_11;    // G2
      cfg.pin_d8 = GPIO_NUM_12;   // G3
      cfg.pin_d9 = GPIO_NUM_13;   // G4
      cfg.pin_d10 = GPIO_NUM_14;   // G5
      cfg.pin_d11 = GPIO_NUM_7;  // R0
      cfg.pin_d12 = GPIO_NUM_17;  // R1
      cfg.pin_d13 = GPIO_NUM_18;  // R2
      cfg.pin_d14 = GPIO_NUM_3;  // R3
      cfg.pin_d15 = GPIO_NUM_46;  // R4

      cfg.pin_henable = GPIO_NUM_42;
      cfg.pin_vsync = GPIO_NUM_41;
      cfg.pin_hsync = GPIO_NUM_40;
      cfg.pin_pclk = GPIO_NUM_39;
      
      cfg.freq_write = 14000000;   

      cfg.hsync_polarity = 1;
      cfg.hsync_pulse_width = 4;
      cfg.hsync_back_porch = 8;
      cfg.hsync_front_porch = 8;

      cfg.vsync_polarity = 1;
      cfg.vsync_pulse_width = 4;
      cfg.vsync_back_porch = 8;
      cfg.vsync_front_porch = 8;

      cfg.pclk_idle_high = 1;

      _bus_instance.config(cfg);
    }
    _panel_instance.setBus(&_bus_instance);



    {
      auto cfg = _touch_instance.config();
      cfg.x_min = 0;
      cfg.x_max = 800;
      cfg.y_min = 0;
      cfg.y_max = 480;
      cfg.pin_int = -1;
      cfg.bus_shared = false;
      cfg.offset_rotation = 0;
      cfg.i2c_port = I2C_NUM_0;
      cfg.pin_sda = GPIO_NUM_15;
      cfg.pin_scl = GPIO_NUM_16;
      cfg.pin_rst = -1;
      cfg.freq = 400000;
      cfg.i2c_addr = 0x5D;  // 0x5D , 0x14
      _touch_instance.config(cfg);
      _panel_instance.setTouch(&_touch_instance);
    }

    setPanel(&_panel_instance);
  }
};

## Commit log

2026-08-27 Initial working ESP32 media player
    [partitions.csv]
2026-08-29 fix: prevent Discord channel label corruption
    [hardware.py, main.py, network.py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]
2026-08-29 fix: make ESP32 readiness handshake reliable
    [hardware.py, main.py, serial_protocol.cpp]
2026-08-29 fix: add framed serial protocol
    [hardware.py, main.py, serial_protocol.cpp]
2026-08-30 fix: improve album art delivery and Discord state responsiveness
    [hardware.py, network.py, serial_protocol.cpp]
2026-08-30 fix: prevent stale album art and improve image updates
    [hardware.py, main.cpp, main.py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]
2026-08-30 fix: correct avatar download error handling
    [network.py]
2026-08-30 feat: swap encoder play-pause and mute controls
    [main.cpp]
2026-08-30 fix: disable scrolling on Discord user cards
    [serial_protocol.cpp]
2026-08-30 feat: improve ESP32 controls and UI transitions
2026-08-30 refactor: extract ESP32 connection handshake
2026-08-30 fix: extend stale album art retry window
    [media.py]
2026-08-31 fix: harden firmware packet handling
    [serial_protocol.cpp]
2026-09-02 fix: quick cleanup of duplicate update media visuals
    [main.cpp]
2026-09-05 docs: prepare project for first public release
    [Complete_Housing_Assembly.f3d, Display_Housing.3mf, Display_Housing_Print.f3d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]
2026-09-05 cleanup: removal of duplicate files
    [Display_Housing_Print.f3d]
2026-09-06 fix: adjusted housing print to better fit micro sd slot, no longer bulges.
    [Complete_Housing_Assembly.f3d, Display_Housing.3mf, Display_Housing_Print.stl]
2026-09-07 fix: duplicate serial packet write and minor cleanup of unecessary lines
    [hardware.py, media.py]
